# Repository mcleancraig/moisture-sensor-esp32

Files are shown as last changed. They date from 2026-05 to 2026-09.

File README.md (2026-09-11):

# Garden Soil Moisture Sensor

Battery-powered wireless soil moisture sensors for garden and indoor plant use. Each unit reads capacitive soil moisture and battery level, publishing data over WiFi/MQTT to a home automation hub. Designed for long-term deployment — estimated 5+ months per charge on a 2000mAh 18650 cell.

Built around the Seeed XIAO ESP32-C6, configured entirely via a captive portal web interface with no hardcoded credentials. Integrates natively with Home Assistant via MQTT autodiscovery.

---

## Features

- Capacitive soil moisture reading (0–100%)
- Battery voltage and percentage monitoring
- WiFi provisioning via captive portal — no hardcoded credentials
- Static or DHCP IP addressing, with configurable gateway, subnet and DNS
- Home Assistant MQTT autodiscovery — sensors appear automatically, autodiscovery republishes daily to recover from broker restarts
- Automatic firmware updates via FOTA from GitHub Releases, with rollback guard after 3 failed boots
- Beta FOTA channel — switch individual sensors between stable and beta firmware streams via Home Assistant
- Sensor power-gating — GPIO cuts HW-390 power during deep sleep, eliminating standby drain
- Syslog — structured UDP syslog to a configurable host for centralised logging
- Boot button reconfiguration — no reflashing needed to change settings
- MQTT command support — send `reset` remotely via retained message
- Deep sleep between readings — configurable interval (default 120 minutes) for long battery life
- First boot delay — skips moisture on first wake (default 15 minutes) so an open-air reading isn't sent while planting
- NTP timestamp in every MQTT payload
- Firmware version reported in every MQTT payload

---

## Wiring diagram

Wiring diagram

---

## Hardware

### Per sensor

| Component | Detail |
|---|---|
| MCU | Seeed XIAO ESP32-C6 |
| Moisture sensor | HW-390 capacitive, 3-pin (VCC / GND / AOUT) |
| Battery | 18650 Li-ion, 2000mAh recommended |
| Reverse polarity protection | None currently — P-channel MOSFET planned (see TODO) |
| Battery voltage divider | 2x 200kOhm resistors (BAT+ to A0 to GND) |
| Sensor power-gating | HW-390 VCC to D4 (GPIO4); configure `sensorPowerPin` in portal |

### Wiring

```
18650 (+) ──────────────────────────── XIAO BAT+ pad
                                        └── 200kOhm ── A0 ── 200kOhm ── GND

18650 (−) ────────────────────────────── XIAO BAT− pad ── GND

HW-390 VCC  ── XIAO D4 (GPIO4)    ← power-gated (see note)
HW-390 GND  ── GND
HW-390 AOUT ── XIAO A1 (GPIO1)
```

After first boot, set **Sensor Power Pin** to `4` in the config portal. The firmware drives D4 HIGH just before the ADC read and LOW before sleeping, so the HW-390 draws no current during deep sleep. Any free GPIO 0–10 can be used; D4 is recommended as it is otherwise unused.

If power-gating is not wired, connect HW-390 VCC to XIAO 3V3 instead and leave Sensor Power Pin at `-1` (default).

The XIAO's onboard charger handles battery charging automatically when USB-C is connected. USB and battery can be connected simultaneously — this is normal and required for charging.

**Note:** No reverse polarity protection is currently fitted. Always check battery orientation before connecting.

---

## Software requirements

### Arduino IDE

Install via the Boards Manager: **esp32 by Espressif Systems**

Board selection: `XIAO_ESP32C6`

### Libraries

Install via the Library Manager:

- **PubSubClient** by Nick O'Leary

All other libraries (`WiFi`, `WebServer`, `DNSServer`, `Preferences`, `HTTPUpdate`, `WiFiClientSecure`, `ESPmDNS`) are included in the ESP32 Arduino core.

---

## Building and flashing

1. Open `moisture-sensor-esp32.ino` in Arduino IDE
2. Select board: **Tools → Board → XIAO_ESP32C6**
3. Connect the sensor via USB-C
4. Select the USB port under **Tools → Port**
5. Click **Upload**

No configuration changes are needed before flashing — all settings are entered via the captive portal after first boot.

---

## First-time setup

On first boot (or after a factory reset), the sensor starts a WiFi access point named:

```
MOISTURE-AABBCC
```

where `AABBCC` is the last three bytes of the device's MAC address in hex.

**To configure:**

1. Connect to the `MOISTURE-` network — password is `moisture`
2. A setup page will appear automatically (captive portal). If it does not, open a browser and navigate to `192.168.4.1`
3. Fill in the form:
   - **Sensor number** — sets the sensor ID (`sensor1`, `sensor2` etc), friendly name, and default static IP last octet
   - **WiFi SSID and password** — your home network credentials
   - **Static IP** — optional. Check the box to assign a fixed IP address. Defaults to `192.168.220.<sensor number>`. When enabled, also configure gateway, subnet mask and DNS
   - **MQTT broker address** — IP address of your MQTT broker (e.g. your Raspberry Pi)
   - **MQTT port** — default 1883
   - **MQTT username / password** — leave blank if your broker does not require authentication
4. Click **Save & Restart**

The sensor will restart, connect to your network, and begin reporting immediately.

**First boot delay:** on the first wake after power-on or portal save, the sensor skips the moisture reading and sleeps for 15 minutes before taking its first full reading. This prevents a misleading open-air reading being sent to Home Assistant while you're getting the sensor into the soil. Battery stats are still published on that first wake. The delay is configurable (0–120 minutes) via the **First Boot Delay** entity in Home Assistant, or disabled by setting it to 0.

If the portal is not used within 10 minutes it will close, the sensor sleeps for 10 minutes, then restarts and tries WiFi again. If WiFi fails on a configured sensor, the portal opens automatically so you can update credentials.

---

## Reconfiguring a deployed sensor

### Boot button (physical access required)

1. Power the sensor on while holding the **boot button** on the XIAO board
2. Hold for 3 seconds until the serial monitor shows `Config — confirmed, clearing config`
3. Release the button — the sensor starts the configuration portal

A brief press under 3 seconds is ignored — normal boot continues.

### MQTT command (fully remote)

Publish a retained message to `garden/sensorN/cmd`. The sensor receives it on its next wake cycle, self-clears the retained message, then acts on it:

```bash
# Reset config and open portal:
mosquitto_pub -h localhost -u USER -P PASS \
  -t "garden/sensor1/cmd" -m "reset" --retain

# Cancel a pending command:
mosquitto_pub -h localhost -u USER -P PASS \
  -t "garden/sensor1/cmd" -m "" --retain
```

From Home Assistant **Developer Tools → Actions → mqtt.publish**:

```yaml
topic: garden/sensor1/cmd
payload: reset
retain: true
```

---

## Home Assistant integration

The sensor uses MQTT autodiscovery. Once MQTT is configured in Home Assistant:

1. Go to **Settings → Devices & Services → MQTT**
2. Ensure **Enable discovery** is checked and the discovery prefix is `homeassistant`
3. On next sensor boot, a new device will appear automatically under **Settings → Devices**

Each sensor creates these entities in Home Assistant:

**Sensors**

| Entity | Unit | Notes |
|---|---|---|
| Moisture | % | Soil moisture level |
| Battery | % | Estimated charge remaining |
| Battery Voltage | V | Raw cell voltage |
| Last Seen | — | NTP timestamp of last reading (UTC) |
| Firmware Version | — | Running firmware version |
| RSSI | dBm | WiFi signal strength at time of reading |
| Battery Low | — | Binary sensor — ON when battery ≤ 15% |

**Controls**

| Entity | Type | Notes |
|---|---|---|
| Reset Config | Button | Clears NVS and opens captive portal on next wake |
| Force check on next wake | Button | Bypasses the 24 h FOTA throttle — triggers an immediate update check |
| Sleep Interval | Number (1–720 min) | Wake cycle duration; default 120 min |
| First Boot Delay | Number (0–120 min) | Delay before first moisture read; default 15 min |
| Update Channel | Select (stable/beta) | FOTA release stream for this sensor |
| Static IP | Switch | Enable/disable static IP addressing |
| MQTT Broker / Port / Username / Password | Text/Number | Remote MQTT config update |
| Syslog Host / Port | Text/Number | Remote syslog config update |
| IP Address / Gateway / Subnet Mask / DNS | Text | Remote network config update |
| Moisture Pin / Battery Pin / Sensor Power Pin | Number | GPIO pin assignments |

The device card also shows the firmware version (`sw_version`) on the device info page.

### MQTT topics

| Topic | Direction | Content |
|---|---|---|
| `garden/sensor1/state` | Sensor → broker | JSON state payload |
| `garden/sensor1/cmd` | Broker → sensor | Command: `reset` (retained) |
| `homeassistant/sensor/sensor1_moisture/config` | Sensor → broker | HA discovery config (retained) |
| `homeassistant/sensor/sensor1_battery_pct/config` | Sensor → broker | HA discovery config (retained) |
| `homeassistant/sensor/sensor1_battery_v/config` | Sensor → broker | HA discovery config (retained) |
| `homeassistant/sensor/sensor1_ts/config` | Sensor → broker | HA discovery config (retained) |
| `homeassistant/sensor/sensor1_fw/config` | Sensor → broker | HA discovery config (retained) |
| `homeassistant/sensor/sensor1_rssi/config` | Sensor → broker | HA discovery config (retained) |
| `homeassistant/binary_sensor/sensor1_battery_low/config` | Sensor → broker | HA discovery config (retained) |
| `homeassistant/button/sensor1_reset/config` | Sensor → broker | HA discovery config (retained) |
| `homeassistant/button/sensor1_update_check/config` | Sensor → broker | HA discovery config (retained) |
| `homeassistant/select/sensor1_fw_channel/config` | Sensor → broker | HA discovery config (retained) |
| `garden/sensor1/update` | Broker → sensor | Retained `1` — forces FOTA check on next wake |

### State payload example

```json
{
  "sensor": "sensor1",
  "moisture": 65,
  "moisture_raw_mv": 1843,
  "dry_mv": 2800,
  "wet_mv": 1000,
  "battery_v": 3.87,
  "battery_pct": 62,
  "battery_raw_mv": 1935,
  "rssi": -67,
  "fw_version": "3.0.2-b01",
  "ts": "2026-05-04T14:32:07Z"
}
```

---

## Firmware updates (FOTA)

On each wake the sensor checks GitHub Releases for a newer firmware version and updates itself automatically. No IDE or physical access needed.

**To release a firmware update:**

1. Bump `FIRMWARE_VERSION` in the sketch
2. Run `build.sh` to compile — output is `build/moisture-sensor-esp32.ino.bin`
3. Create a plain text file `version.txt` containing just the new version number (e.g. `3.0.2`) with no trailing newline
4. Create a new GitHub release tagged `vX.X.X`, attach both `moisture-sensor-esp32.ino.bin` and `version.txt` as release assets
5. Every sensor will pick up the update automatically on its next wake cycle

The `fw_version` field in the MQTT payload confirms the running firmware version. If an update fails the sensor continues operating on the existing firmware and retries on the next wake.

**FOTA rollback guard:** after a FOTA flash, the firmware counts consecutive failed boots (defined as wakes that do not complete a successful MQTT publish). After 3 failures it switches back to the previous OTA partition and logs `FOTA — ROLLED BACK` via syslog. The rejected version is blocked from re-downloading.

**Update Channel:** each sensor can independently follow the `stable` channel (GitHub Releases marked *Latest*) or the `beta` channel (most recent release including pre-releases). Switch a sensor by changing its **Update Channel** entity in Home Assistant — the new value is written to NVS on next wake. Default is `stable`.

**Force check on next wake:** pressing the **Force check on next wake** button in HA publishes a retained `1` to `garden/sensorN/update`. The sensor reads this on its next wake, clears the retained message, and runs a FOTA check immediately regardless of the 24 h throttle.

**Tagging and releasing from the command line:**

```bash
git tag -a v3.0.3 -m "v3.0.3 release notes here"
git push origin v3.0.3
```

Then on GitHub go to **Releases → Draft a new release**, select the tag, and attach `moisture-sensor-esp32.ino.bin` and `version.txt`.

---

## Beta releases

Riskier changes can be shipped to a subset of sensors first via the **beta FOTA channel** before promoting to the whole fleet. The two channels read different sources, which is why their release assets differ:

| Channel | Reads | Assets required |
|---|---|---|
| `stable` | `/releases/latest/download/version.txt`, then the binary from the same release | `moisture-sensor-esp32.ino.bin` **and** `version.txt` |
| `beta` | `tag_name` of the newest release via the GitHub API, including pre-releases | `moisture-sensor-esp32.ino.bin` only |

**To cut a beta:**

1. On the version branch (not `main`), set `FIRMWARE_VERSION` to `X.Y.Z-bNN` — e.g. `3.0.3-b01`; bump `NN` for a respin
2. Tag and push: `git tag -a v3.0.3-b01 -m "..." && git push origin v3.0.3-b01`
3. Draft a release from that tag, tick **Set as a pre-release**, and attach the `.bin`. No `version.txt` needed — the beta channel never reads it, and `/releases/latest` skips pre-releases so stable sensors are unaffected
4. Sensors with **Update Channel** set to `beta` pick it up on their next wake

**To promote a confirmed beta to stable:**

1. On the version branch, drop the `-bNN` suffix from `FIRMWARE_VERSION`
2. Finalise the `CHANGELOG.md` entry
3. Open the final PR from the version branch into `main` and merge
4. Tag and release as normal (`vX.Y.Z`, *not* a pre-release), attaching both the `.bin` and `version.txt`

`isNewerVersion()` treats a stable build as newer than a beta of the same version, and a higher `-bNN` as newer than a lower one, so promoting to stable is picked up automatically and switching a sensor's channel back and forth needs no version bump.

**Attach the binary before publishing, not after.** The beta channel bypasses the 24 h FOTA throttle, so a published pre-release with no `.bin` attached leaves beta sensors retrying a 404 on *every* wake.

**Verify the binary before uploading** — confirm the version baked into it matches the tag:

```bash
grep -a -o '3\.0\.3[^"]*' build/moisture-sensor-esp32.ino.bin | sort -u
```

A mismatch here means every sensor will download the "new" firmware, boot into the old version, see an update available again, and reflash indefinitely.

**Beta sensors park when no pre-release is newest.** If the most recent release is a stable one, beta-channel sensors log `FOTA — no beta release available yet, staying put` and hold their current build rather than moving to the stable. To bring them back in line with the fleet, switch their **Update Channel** to `stable`.

---

## Syslog

The sensor buffers log messages during its wake cycle and flushes them over UDP syslog after WiFi connects. This gives centralised, structured logging without a serial connection.

**Configuration:** set `Syslog Host` and `Syslog Port` in the captive portal, or update them remotely via the corresponding HA entities. Default port is `514`. Leave `Syslog Host` blank to disable syslog.

**Behaviour:**
- All `logf()` calls are buffered in RAM during boot and WiFi connection
- After WiFi connects the buffer is flushed: each entry is sent as a syslog UDP packet to the configured host
- If DNS resolution fails for the syslog host the buffer is discarded and syslog is skipped for that cycle (no startup delay)
- After flush, any subsequent log calls are sent immediately

**Useful log patterns:**
- `FOTA      — ROLLED BACK` — firmware rollback guard fired; investigate what changed
- `Discovery — skipped (3.0.3, NNm ago)` — discovery republish throttled; expected on most wakes
- `FOTA      — forced check` — triggered by the Force check HA button
- `WiFi      — connected, IP: … (312ms, cached)` — association time, and whether the cached BSSID or a full scan was used. A sensor logging `full scan` every wake is not benefiting from the connection cache
- `WiFi      — fast connect failed, retrying full scan connect` — the cached AP moved channel or went away; self-corrects, but persistent occurrences suggest an unstable AP or roaming between mesh nodes
- `Sleep     — awake NNNNms this wake` — total awake duration. The single most useful number for tracking per-wake energy use across the fleet
- `MQTT      — listen window closed after NNNms (N message(s) this wake)` — confirms remote commands are arriving inside the listen window

---

## Moisture sensor calibration

The HW-390 sensor must be calibrated once per unit for accurate percentage readings. The raw millivolt values are included in every MQTT payload (`moisture_raw_mv`) to assist with this.

**Calibration procedure:**

1. Flash the firmware and configure the sensor
2. Hold the sensor in open air — note the stable `moisture_raw_mv` value. Set this as `DRY_MV` in the firmware (typically ~2800mV)
3. Submerge the sensor to the white line marked on the PCB — note the stable value. Set this as `WET_MV` (typically ~1000mV)
4. Reflash with updated values

The HW-390 is inverted: dry soil reads a higher millivolt value than wet soil. `DRY_MV` should always be greater than `WET_MV`.

---

## Battery life

Based on a 120-minute sleep cycle (default) and 2000mAh cell:

| Phase | Current | Duration per cycle |
|---|---|---|
| Deep sleep | ~15uA | ~7,195 seconds |
| WiFi + MQTT | ~300mA peak | ~3 seconds |
| FOTA version check | ~80mA | ~2 seconds (no download if firmware is current) |

Estimated runtime: **5+ months** per charge. Actual runtime depends on WiFi signal strength, temperature, and cell quality.

The awake duration above is an estimate. Since v3.0.3 the real figure is logged every wake as `Sleep — awake NNNNms this wake`, so per-sensor energy use can be measured from syslog rather than assumed — worth checking against this table before making further power optimisations. Note that at a 120-minute interval, standby losses (deep sleep current, the 400 kΩ battery divider, regulator quiescent draw and cell self-discharge) are a substantial share of the budget, so reducing awake time has diminishing returns compared with cutting standby draw.

The battery percentage uses a piecewise linear interpolation of a real 18650 discharge curve, giving accurate readings across the full voltage range rather than fixed steps.

---

## Factory reset

To completely clear all configuration and return to first-boot state:

- **Via MQTT:** send a retained `reset` command (see Reconfiguring a deployed sensor above) — no physical access needed
- **Via boot button:** power the sensor on while holding the boot button for 3 seconds — the firmware clears NVS and starts the configuration portal. No reflashing required

---

## Deploying multiple sensors

Each sensor needs only one change — the sensor number is set during portal configuration and everything else derives from it automatically:

| Sensor number | Sensor ID | MQTT topic | Default static IP |
|---|---|---|---|
| 1 | sensor1 | garden/sensor1/state | 192.168.220.1 |
| 2 | sensor2 | garden/sensor2/state | 192.168.220.2 |
| 3 | sensor3 | garden/sensor3/state | 192.168.220.3 |

Each sensor must be calibrated individually as HW-390 units vary slightly from one another.

---

## Troubleshooting

**Sensor not appearing in Home Assistant**
Ensure MQTT integration is enabled in HA and discovery is turned on. Check the broker is reachable and credentials are correct by monitoring `garden/#` on the broker directly:

```bash
mosquitto_sub -h localhost -t "garden/#" -v -u YOUR_USER -P YOUR_PASSWORD
```

**FOTA update not applying**
- Ensure the sensor has internet access — verify DNS is configured correctly in the portal
- Check the `fw_version` field in the MQTT payload to confirm what version is currently running, and the sensor's **Update Channel** to confirm which stream it is following
- *Stable channel:* confirm `version.txt` is attached to the latest GitHub release and contains the correct version string with no leading `v` and no trailing whitespace or newlines. A leading `v` will not parse and the sensor will never update
- *Beta channel:* confirm the newest release is marked as a pre-release. If the newest release is a stable one, beta sensors deliberately stay put — see [Beta releases](#beta-releases)

**Sensor reflashing on every wake**
The version baked into the released binary does not match the release it is attached to, so the sensor downloads it, boots reporting the old version, and immediately sees an update available again. Check syslog for a repeating `FOTA — update available: X -> Y` where `X` never changes, then verify the release asset as described under [Beta releases](#beta-releases) and re-upload a correctly built binary. Sensors recover on their own once the corrected asset is in place.

**Moisture reading stuck at 0% or 100%**
Recalibrate — the `DRY_MV` and `WET_MV` values in the firmware need to match your specific sensor unit. Check `moisture_raw_mv` in the MQTT payload and compare against your calibration readings.

**Battery reading shows null**
The battery reading falls outside the sanity check range (2.5V–4.3V). Check the voltage divider wiring — two 200kOhm resistors from BAT+ to A0 to GND. Confirm A0 is the pin connected to the midpoint, not A1.

**Sensor getting hot when USB connected**
Check battery polarity. Overheating is caused by reverse polarity on the battery connection, not by USB and battery being connected simultaneously. USB and battery can safely coexist — the onboard charger is designed for this. No polarity protection is currently fitted — always check battery orientation carefully before connecting.

---

## Licence

GPL V2 — see LICENSE.md

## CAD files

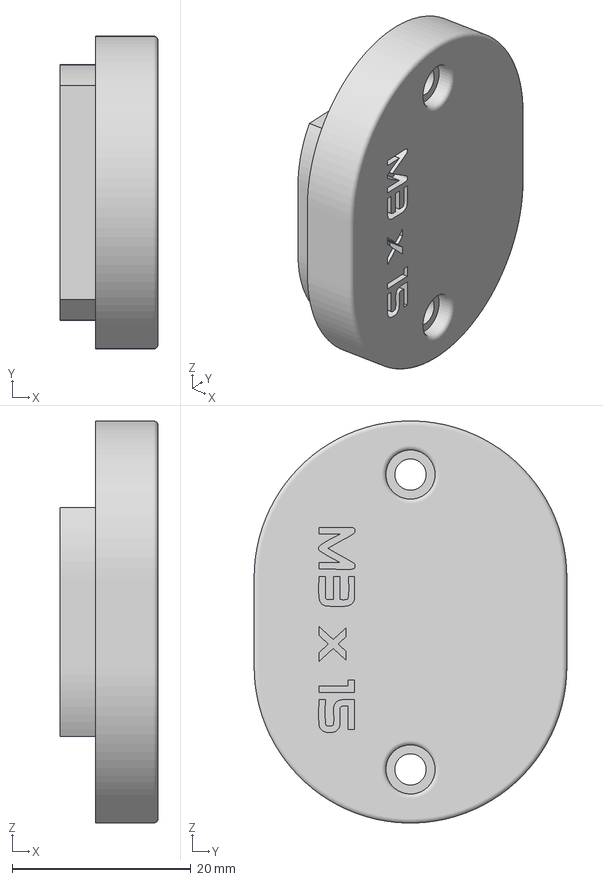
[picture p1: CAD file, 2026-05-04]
3d-printed-case/Lid.3mf
11.0 x 35.0 x 45.0 mm

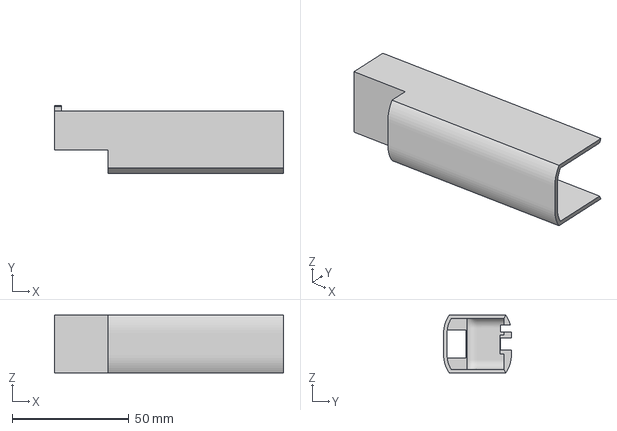
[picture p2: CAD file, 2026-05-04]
3d-printed-case/Tray.3mf
98.0 x 29.0 x 24.7 mm

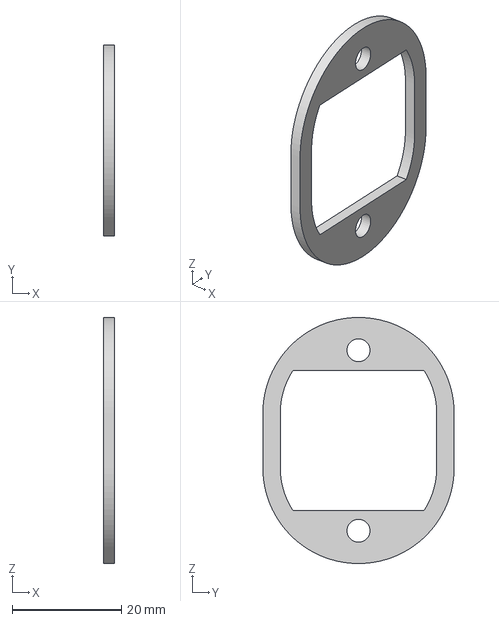
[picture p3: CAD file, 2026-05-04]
3d-printed-case/Seal.3mf
2.00 x 35.0 x 45.0 mm

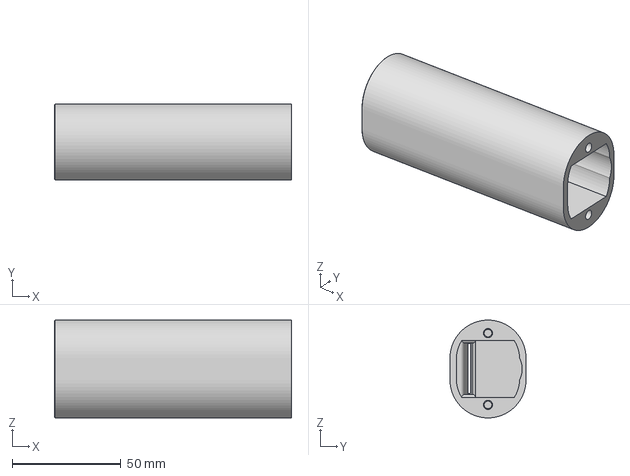
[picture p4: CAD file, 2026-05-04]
3d-printed-case/Case.3mf
109.0 x 35.0 x 45.0 mm

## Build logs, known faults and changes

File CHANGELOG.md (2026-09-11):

# Changelog

All notable changes to moisture-sensor-esp32 are documented here.
Format follows [Keep a Changelog](https://keepachangelog.com/).

## [3.0.3] — 2026-09-11

### Fixed
- **HA discovery republished on every wake** — the safety-net threshold was `> 2h`, exactly equal to the default `SLEEP_MINUTES` of 120, so elapsed time always exceeded it and the throttle never fired. Roughly 20 retained discovery payloads were being republished every wake instead of acting as an occasional recovery mechanism, and the `Discovery — skipped` log line was effectively unreachable. Now governed by `DISCOVERY_REPUBLISH_S` (24h), which stays clear of the longest configurable `sleepMinutes` (720).

### Changed
- **MQTT listen window shortened, 2000ms → 750ms** — retained commands are delivered within tens of milliseconds of SUBACK, so the old fixed 2s window spent most of its time idle at full radio power. Each inbound message now extends the window by 250ms (capped at 2000ms, the previous fixed value), so a burst of `config/set` fields published together is still captured in a single wake. Worst-case awake time is unchanged; typical awake time drops by ~1.25s per wake.

### Added
- **Wake timing instrumentation** — `WiFi — connected` now reports association time and whether the cached BSSID or a full scan was used; a new `Sleep — awake Nms this wake` line reports total awake duration. Both are intended for measuring per-wake energy across the fleet from syslog.

### Upgrade notes
- Discovery now republishes at most daily rather than every 2 hours. After an MQTT broker restart that loses retained messages, Home Assistant may show a sensor as unavailable for up to 24h. A firmware update or power cycle forces an immediate republish, as before.

## [3.0.1-b02] — 2026-07-04

### Added
- **Captive Portal Update Channel Selection (`fwChannel`)** — Exposed the 'Update channel' selection dropdown (stable/beta) in the captive portal's Advanced Settings. Dynamically pre-selects 'beta' on setup if booting a pre-release/beta build (preventing accidental downgrades back to stable), while giving the user full control to save their preferred channel.

### Removed
- **Unused Reed Switch Code** — Completely removed the unused reed switch monitoring, including the configuration struct parameter, load/save logic, captive portal form inputs, JavaScript client-side validation, server-side parsing, dynamic MQTT parsing, and the `checkReedSwitch()` function. Physical pin **D2** (GPIO 2) is now completely clean and unassigned, making it 100% safe to configure as the **Sensor Power Pin** to power-gate the soil moisture sensor without boot loop risks or false conflict checks.

## [3.0.1-b01] — 2026-07-04

### Added
- **Configurable On-Demand Sensor Power Pin (`sensorPowerPin`)** — Adds support for powering the soil moisture sensor via a configurable GPIO pin (NVS key `powerPin`, defaults to `-1` for continuous rail power).
- **Parallel Power Stabilization** — Drives the sensor power pin `HIGH` early during boot to overlap the 500ms stabilization period with other boot checks, minimizing wake time. Bypasses the 500ms delay and uses a quick 200ms settling window when running off the continuous rail.
- **Deep Sleep Tri-stating** — Drives the power pin `LOW` and sets it to high-impedance `INPUT` mode (tri-state) during deep sleep to completely eliminate parasitic leakage current.
- **Beta FOTA Rate-Limit Bypass** — Bypasses the 24-hour rate limit gate for sensors subscribed to the `beta` update channel or running a beta/dev firmware version, allowing update checks on every boot.

### Changed
- **Smart Pin-Conflict Checking** — Updated both boot validation, captive portal client/server validation, and MQTT remote config pin conflict checking to safely skip negative (disabled) pins, preventing false conflicts.

## [3.0.0] — 2026-07-04

### Added
- **Wi-Fi Fast Connect Caching** — Implemented caching of successful Wi-Fi channel and BSSID in RTC SRAM. Speeds up subsequent connection attempts to ~200ms under optimal conditions.
- **Deep Sleep GPIO Pull-up Hold** — Maintains the Reed switch internal pull-up during deep sleep to prevent spurious wakeups, using conditional compilation to support the ESP32-C6's single-pin hold mechanism.
- **Sleep Interval MQTT/HA control** — `config/set/sleepMinutes` and a "Sleep Interval" number entity (1-720 min) let you change how long the sensor sleeps between wake cycles without reflashing.

### Changed
- **Home Assistant Discovery Topic Refactoring** — Removed 25 redundant global `char[128]` buffer arrays, saving **3,200 bytes of permanent dynamic RAM (BSS)**. Discovery topics are now formatted dynamically on-the-fly.
- **Shared Device JSON Helper** — Extracted duplicate Home Assistant `device` JSON construction logic into a static `getDeviceJSON()` helper function, saving **914 bytes of program Flash memory**.
- **Consolidated Telemetry JSON Construction** — Replaced three duplicate, verbose `snprintf()` blocks in `setup()` with a clean conditional single-pass composer, reducing Flash footprint.
- **Log Buffer & Stack Optimization** — Removed the redundant `char sysline[120]` stack buffer from `_logf()`, reducing active stack overhead by **120 bytes** for all print operations.
- **Secure FOTA Certificate Bundle** — Replaced `client.setInsecure()` with secure validation using ESP32's built-in root CA certificate bundle (`esp_crt_bundle_attach` via a `SecureClient` wrapper) to properly and safely validate HTTPS connections and redirects.
- **"Update on next wake" button renamed "Force check on next wake"** — Renamed this control under a clearer name.

### Removed
- **Restart MQTT/HA control** — the Restart button and `garden/sensorN/cmd` `restart` command are gone. No longer applicable now the device already restarts every wake as part of its normal sleep cycle. `reset` (full config wipe + portal) is unaffected.
- **Reed Switch Pin MQTT/HA control** — the "Reed Switch Pin" number entity and `config/set/reedPin` are gone. `reedPin` is now portal-only, matching `wifiSSID`/`unitNumber`. The reed switch itself (hold 3s to restart, hold 10s to wipe config, GPIO wakeup) is unchanged.

### Upgrade notes
- After every sensor is running v3.0.0+, run `cleanup-mqtt-retained.sh` against your broker to clear the retained Restart button discovery config and the Reed Switch Pin discovery config — neither is republished or cleared automatically by the firmware change alone.

## [3.0.0-b04] — 2026-07-04

### Changed
- **Home Assistant Discovery Topic Refactoring** — Removed 25 redundant global `char[128]` buffer arrays, saving **3,200 bytes of permanent dynamic RAM (BSS)**. Discovery topics are now formatted dynamically on-the-fly.
- **Shared Device JSON Helper** — Extracted duplicate Home Assistant `device` JSON construction logic into a static `getDeviceJSON()` helper function, saving **914 bytes of program Flash memory**.
- **Consolidated Telemetry JSON Construction** — Replaced three duplicate, verbose `snprintf()` blocks in `setup()` with a clean conditional single-pass composer, reducing Flash footprint.
- **Log Buffer & Stack Optimization** — Removed the redundant `char sysline[120]` stack buffer from `_logf()`, reducing active stack overhead by **120 bytes** for all print operations.

## [3.0.0-b03] — 2026-07-04

### Added
- **Wi-Fi Fast Connect Caching (Optimization 2)** — Implemented caching of successful Wi-Fi channel and BSSID in RTC SRAM. Speeds up subsequent connection attempts to ~200ms under optimal conditions, falling back to a full scan if fast connect fails within 4 seconds.
- **Deep Sleep GPIO Pull-up Hold (Optimization 4)** — Maintains the Reed switch internal pull-up during deep sleep to prevent spurious wakeups, using conditional compilation to support the ESP32-C6's single-pin hold mechanism.

### Changed
- **Secure FOTA Certificate Bundle (Optimization 3)** — Replaced `client.setInsecure()` with secure validation using ESP32's built-in root CA certificate bundle (`esp_crt_bundle_attach` via a `SecureClient` wrapper) to properly and safely validate HTTPS connections and redirects.

## [2.11.0] — 2026-07-01

### Fixed
- **NVS magic regression (v2.10.2)**: absent magic (sensors configured before v2.5.3 that never triggered a config change post-upgrade) now proceeds normally again instead of wiping NVS. Magic is written passively at the end of a successful `loadConfig()` so the migration happens on the next boot without any portal interaction. Wrong-value magic still wipes NVS as before.
- **First boot delay disabled after portal re-provision**: `handleSave()` was copying `firstBootDelayMin` from `cfg` even when `loadConfig()` had returned early (after a magic wipe), leaving `cfg` zero-initialised and silently saving `firstBootDelayMin = 0`. Now uses the 15-minute default when config was never loaded, preserving an explicit user value when it was.

### Changed
- **Portal AP name**: shortened from full 12-char MAC (`MOISTURE_AABBCCDDEEFF`) to last-3-bytes short form (`MOISTURE-DDEEFF`) — unique per device, much easier to distinguish when multiple sensors are in portal mode simultaneously.
- **Boot logging**: `reset_reason` now includes human-readable string (`POWERON`, `SW`, `PANIC`, `WDT`, `BROWNOUT`, …). A new log line on cold boots and portal-restarts confirms whether the first boot delay is active and the configured value.
- **Sleep log reliability**: `goToSleep()` now waits 50 ms after logging before calling `esp_deep_sleep_start()`, giving the final syslog UDP packet time to transmit before the radio shuts down.

## [2.10.2] — 2026-05-27

### Changed
- NVS magic check tightened: absent magic key now clears the namespace and falls through to portal, matching the behaviour for a wrong-value magic key. Previously, absent magic was left alone for backwards compatibility with pre-2.5.3 sensors. All deployed sensors have run 2.5.3+ for some time.

## [2.10.1] — 2026-05-27

### Fixed
- `handleSave()` built `Config c = {}` (zero-initialised), saving `firstBootDelayMin = 0` to NVS and discarding the 15-minute default. Fixed: `handleSave()` now copies `firstBootDelayMin` from `cfg` before saving.
- Post-portal `ESP.restart()` gives `reset_reason = SW (3)`, not `POWERON (1)`, so the first operational boot after configuring a new sensor never triggered the delay. Fixed with a one-shot NVS flag (`firstBootPend`) set by `handleSave()` and atomically read and cleared by `checkAndClearFirstBootPending()` at next boot.

## [2.10.0] — 2026-05-27

### Added
- **First boot delay** — on power-cycle (`ESP_RST_POWERON`) or immediately after portal configuration, the device publishes all stats except moisture then sleeps for `firstBootDelayMin` (default 15 minutes) before waking for the first full reading. Prevents a spurious near-zero moisture reading while the sensor is still in open air after battery insertion.
- `firstBootDelayMin` config field (NVS key `firstBootMin`, default 15, range 0–120 minutes). Set to 0 to disable.
- HA `First Boot Delay` number entity (0–120 min) via autodiscovery.
- MQTT remote config: `config/set/firstBootDelayMin` — same pattern as all other configurable fields.

### Changed
- `goToSleep()` now takes an explicit `int minutes` parameter (was hardcoded to `SLEEP_MINUTES`).

## [2.9.0] — 2026-05-16

### Changed
- `sensorNumber` renamed to `unitNumber` in config struct for cross-repo consistency (NVS key `sensorNum` unchanged — no factory reset required)
- State payload field `"fw"` renamed to `"fw_version"` — update any HA value templates that reference `value_json.fw`
- FOTA version comparison now uses integer semver parsing — fixes `"2.10.0" < "2.9.0"` bug under lexicographic `strcmp`
- Beta channel FOTA now uses strict `isNewerVersion()` instead of `!=` — prevents downgrade if remote beta is older

### Added
- `"rssi"` field in state payload (WiFi RSSI in dBm)
- Full wake-reason switch: timer, GPIO, and unexpected causes all logged with reason codes
- `esp_reset_reason()` logged at boot — surfaces panics, WDT resets, and brownouts in syslog
- Heap monitoring: free + minimum free heap logged after WiFi connects and after FOTA check
- `validateConfig()` called at boot to warn of GPIO pin conflicts
- `"MQTT — HA discovery published"` log line after all discovery payloads sent
- MQTT connect log now includes port number
- `*.bin` added to `.gitignore`
- `CHANGELOG.md` and `build.sh`

## [2.8.0] — 2026-05-15

### Added
- Beta FOTA channel — opt sensors into pre-releases via HA select entity
- Force-update via MQTT — `garden/sensorN/update` retained flag triggers immediate FOTA check on next wake
- HA button entity for firmware update

### Changed
- Sleep interval restored to 120 minutes
- FOTA moved after MQTT listen phase so force-update command takes effect same wake

## [2.7.0]

### Changed
- NTP re-sync skipped when RTC already holds valid time (saves ~8 s per wake)
- FOTA version check throttled to once per 24 h via RTC memory timestamp
- HA discovery publish skipped on normal deep-sleep wakes (republishes on cold boot or after 7 days)

## [2.6.2]

### Changed
- Sleep interval increased from 15 to 120 minutes

## [2.6.1]

### Fixed
- Reed switch default pin changed from GPIO3 to GPIO2 (GPIO3 non-functional as digital input on XIAO ESP32-C6)

## [2.6.0]

### Added
- Reed switch GPIO wakeup — device wakes within ms of magnet contact, enabling reliable 3 s/10 s hold timing

## [2.5.3]

### Added
- NVS magic key validation — detects stale config from foreign firmware and falls through to portal

[2.11.0]: https://github.com/mcleancraig/moisture-sensor-esp32/releases/tag/v2.11.0
[2.10.2]: https://github.com/mcleancraig/moisture-sensor-esp32/releases/tag/v2.10.2
[2.10.1]: https://github.com/mcleancraig/moisture-sensor-esp32/releases/tag/v2.10.1
[2.10.0]: https://github.com/mcleancraig/moisture-sensor-esp32/releases/tag/v2.10.0
[2.9.0]: https://github.com/mcleancraig/moisture-sensor-esp32/releases/tag/v2.9.0
[2.8.0]: https://github.com/mcleancraig/moisture-sensor-esp32/releases/tag/v2.8.0

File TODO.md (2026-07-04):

# TODO — v3 and beyond

Items identified during v2 development for future releases.

## Security

- [ ] **FOTA TLS certificate validation** — `checkForUpdate()` currently uses `client.setInsecure()`, which skips certificate verification. An MITM on the network path between the sensor and GitHub could serve a malicious firmware binary that the device would flash without question. Fix: embed the ISRG Root X1 CA certificate (~1.5 KB of flash) and call `client.setCACert(rootCA)` instead. This secures the entire download path without requiring manual cert rotation.

- [ ] **FOTA firmware integrity check** — even with TLS validation, publishing a SHA-256 hash of `firmware.bin` as a third release asset and verifying it before flashing would provide defence-in-depth against a compromised GitHub account or release. Requires downloading the binary manually rather than via `httpUpdate`, then verifying the hash before calling `Update.begin()`.

- [ ] **P-channel MOSFET reverse polarity protection** — replace the removed 1N5819 diode with a P-channel MOSFET (e.g. AO3401) wired as a reverse polarity switch. Unlike the diode this has near-zero voltage drop and allows bidirectional current, meaning charging works correctly while still protecting against reversed battery insertion. The 1N5819 diode blocked charging current and has been removed from the design pending this fix.

## Maintainability

- [x] **NVS magic — migrate pre-2.5.3 sensors (v2.11.0)** — v2.10.2's clear-on-absent tightening turned out to wipe sensors that had run pre-2.5.3 firmware and never since triggered a config save, so v2.11.0 reverted it: absent magic now proceeds normally and is written passively at the end of a successful `loadConfig()`, migrating those sensors on their next boot with no portal interaction. Wrong-value magic still clears NVS as before.

- [x] **FOTA (v2.1.0)** — sensors automatically check GitHub Releases on each wake and self-update. Attach `version.txt` and `firmware.bin` to each release. IDE-based OTA removed.

- [ ] **PCB design** — replace breadboard/perfboard wiring with a custom 2-layer PCB. Castellated footprint for the XIAO ESP32-C6, HW-390 JST connector, 2x 200k voltage divider resistors, 100nF bypass cap, BAT+/BAT- pads. Fabricate via JLCPCB. Reduces assembly time per unit from ~30 min to ~5 min.

## Power

- [ ] **Power-gate the soil moisture sensor** — the HW-390's VCC is wired directly to the 3V3 rail, drawing 5–10 mA continuously including during deep sleep. Fix: wire sensor VCC to a free GPIO (e.g. GPIO4), drive it HIGH just before the ADC read, wait ~80 ms to stabilise, sample, then pull LOW before sleeping. Reduces deep-sleep current from ~5000 µA to ~20 µA — a 99.6% saving. Add `moisturePowerPin` as a config field (portal + NVS) so the pin can be set per-unit without reflashing.

## Scalability

- [ ] **Zigbee mesh migration** — the ESP32-C6 supports Zigbee 3.0 natively. For deployments beyond 15 sensors, or where battery life becomes a concern, reflash units as Zigbee end devices with one unit acting as coordinator (USB-powered, connected to Pi). Requires ESP-IDF rather than Arduino. Zigbee transmit current is significantly lower than WiFi, extending battery life considerably.

## Nice to have

- [x] **Wiring diagram** — SVG diagram in repo showing XIAO ESP32-C6, 18650, HW-390, voltage divider, and reed switch. Photos still outstanding (see below).

- [-] ~~**Reed switch testing**~~ *(skipped)* — two-stage hold (3 s = restart, 10 s = wipe config) implemented in v2.4.1 but untested on real hardware.

- [ ] **Photos** — add photos of the assembled unit, enclosure, and deployed sensor to the README.

- [ ] **Calibration helper** — add a calibration mode triggered by double-tap of the boot button that holds the sensor awake, streams raw ADC readings over serial, and publishes min/max observed values to MQTT to assist with DRY_MV / WET_MV calibration without reflashing.

- [x] **Low battery alert** — binary sensor autodiscovery entity, reports ON at ≤ 15% (v2.4.1).

- [x] **FOTA downgrade protection** — implemented in v2.9.0; `isNewerVersion()` uses numeric semver comparison and only updates when remote > local.

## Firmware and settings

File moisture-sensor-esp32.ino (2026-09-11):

#include <WiFi.h>
#include <WiFiUDP.h>
#include <WebServer.h>
#include <DNSServer.h>
#include <Preferences.h>
#include <PubSubClient.h>
#include <HTTPUpdate.h>
#include <WiFiClientSecure.h>
#include <time.h>
#include "esp_mac.h"
#include "esp_sleep.h"
#include "esp_ota_ops.h"
#include "esp_partition.h"
#include <esp_crt_bundle.h>
#include <driver/gpio.h>

class SecureClient : public WiFiClientSecure {
public:
  void enableDefaultBundle() {
    attach_ssl_certificate_bundle(sslclient.get(), true);
    _use_ca_bundle = true;
    _use_insecure = false;
  }
};

// ═══════════════════════════════════════════════════════════
//  v3.0.2
//  - MQTT autodiscovery republish interval reduced from 7 days
//    to 2 hours. HA entities now recover within one wake cycle
//    after a broker restart or retained-message loss.
//  - Fix: %% corrected to % in moisture and battery_pct
//    unit_of_measurement discovery payloads. HA was rejecting
//    these entity configs due to the literal %% in the JSON.
//  - Fix: forward declarations added for _logf and hasValidEpoch
//    to allow compilation on Apple Silicon without Rosetta.
// ═══════════════════════════════════════════════════════════
//  v3.0.1
//  - Completely removed the unused Reed Switch code, including
//    the portal input fields, JavaScript/server-side validation,
//    dynamic MQTT configuration parsing, and the checkReedSwitch()
//    loop.
//  - Physical pin D2 (GPIO 2) is now fully unassigned and can
//    be safely used for sensor power gating (configured as Sensor
//    Power Pin = 2) without boot loop risks or conflict checks.
// ═══════════════════════════════════════════════════════════
//  v3.0.0
//  - Removed the Restart MQTT/HA control (button + garden/sensorN/cmd
//    "restart" command). No longer applicable now the device already
//    restarts every wake as part of the sleep cycle.
//  - Removed the Reed Switch Pin MQTT/HA control (config/set/reedPin +
//    HA number entity). The reed switch itself — hold-to-restart,
//    hold-to-wipe, GPIO wakeup, portal field — is unchanged; reedPin is
//    now portal-only, matching wifiSSID/unitNumber.
//  - Update-on-next-wake button renamed "Force check on next wake" for
//    clarity (b01 removed it, reasoning routine FOTA already checks every
//    wake — but that check is throttled to once per 24h, and this button
//    is the only way to bypass the throttle on demand, e.g. right after
//    cutting a beta for a test device. Restored in b02.)
//  - Added Sleep Interval MQTT/HA control (config/set/sleepMinutes,
//    "Sleep Interval" number entity, 1-720 min) — replaces the hardcoded
//    SLEEP_MINUTES constant as the default.
//  - See cleanup-mqtt-retained.sh to clear retained broker state left by
//    the Restart button, Reed Switch Pin control, and remote config command
//    topics once the fleet is on v3.0.1+.
//
//  v2.11.0
//  - NVS magic: revert v2.10.2 tightening for the absent-magic case.
//    Absent magic (pre-2.5.3 sensors that never called saveConfig()) now
//    proceeds normally again and writes magic at the end of a successful
//    loadConfig(). Wrong-value magic still clears NVS as before. This fixes
//    the v2.10.2 regression that wiped sensors configured before 2.5.3 that
//    had never triggered a config change since upgrading.
//  - First boot delay: fix handleSave() copying firstBootDelayMin from an
//    uninitialised cfg when loadConfig() returned early (magic wipe). Now
//    uses 15-minute default when config was never loaded, preserving an
//    explicit user setting when it was. This also fixes the linked issue
//    where post-wipe portal provisioning silently disabled the delay.
//  - Portal AP name: shortened from full 12-char MAC to last-3-bytes
//    (MOISTURE-AABBCC) — unique per device, easier to distinguish when
//    multiple sensors are in portal mode simultaneously.
//  - Boot logging: reset_reason now includes human-readable string
//    (POWERON, SW, PANIC, WDT, BROWNOUT, …). A new log line on cold
//    boots/portal-restarts confirms whether first boot delay is active and
//    the configured value — directly visible in syslog without inference.
//  - Sleep log: added delay(50) in goToSleep() to give the final syslog
//    UDP packet time to transmit before the radio shuts down.
//
//  v2.10.2
//  - NVS magic tightened: absent magic key (pre-2.5.3 sensors) now clears
//    the namespace and falls through to portal, matching the existing
//    wrong-value behaviour. Backwards-compatibility holdover removed now
//    that all deployed sensors have run 2.5.3+.
//
//  v2.10.1
//  - First boot delay bug fixes:
//    (a) handleSave() built Config c={} (zero-init), writing firstBootDelayMin=0
//        to NVS and discarding the 15-min default. Fixed: handleSave() now
//        copies firstBootDelayMin from the current cfg before saving.
//    (b) After portal config, ESP.restart() produces reset_reason=SW (3), not
//        ESP_RST_POWERON (1), so the post-portal boot never triggered the delay.
//        Fixed: handleSave() sets a one-shot NVS flag (firstBootPend); setup()
//        checks both ESP_RST_POWERON and that flag to determine isFirstBootDelay.
//
//  v2.10.0
//  - First boot delay: on power-cycle cold boot the device publishes all
//    stats except moisture, then sleeps for firstBootDelayMin (default 15)
//    before waking for the first full data set. This prevents a spurious
//    near-zero moisture reading while the sensor is still in open air after
//    battery insertion. firstBootDelayMin is configurable via HA/MQTT
//    (0 = disabled). Only triggered by ESP_RST_POWERON; warm resets and
//    deep-sleep wakes follow the normal cycle.
//
//  v2.9.0
//  - Cross-repo standardisation:
//    sensorNumber renamed to unitNumber (NVS key unchanged — no factory reset);
//    state payload fw → fw_version, add rssi field;
//    semver comparison fixed (strcmp fails when minor ≥ 10);
//    full wake/reset-reason logging (timer, GPIO, cold boot, panics);
//    heap monitoring at boot and post-FOTA;
//    validateConfig() pin-conflict check at boot;
//    HA discovery published log; MQTT connect log includes port.
//
//  v2.8.0
//  - Beta FOTA channel: sensors can be switched to "beta" update channel
//    via HA, which tracks GitHub pre-releases (tagged 2.8.0-b01 etc.) rather
//    than stable releases only. Version comparison on beta channel uses
//    "different = update" semantics; stable channel unchanged.
//  - Update on next wake: HA button publishes a retained MQTT flag to a
//    dedicated topic; device receives it on next wake, clears the flag, and
//    runs a FOTA check unconditionally (bypasses 24h gate and dev-build guard).
//  - FOTA moved to after the MQTT listen phase so the force-update command
//    received this wake takes effect this wake, not the next.
//  - fwChannel config field persisted in NVS; exposed as HA select entity.
//
//  v2.7.0
//  - Power optimisation: NTP re-sync skipped when ESP32 RTC already holds a
//    valid time from the previous cycle (deep sleep preserves RTC). Full NTP
//    sync forced once every 24 hours to correct clock drift.
//  - Power optimisation: FOTA version check throttled to once per 24 hours
//    via RTC memory timestamp. Eliminates a TLS connection (~8s) on every
//    wake when firmware is already current.
//  - Power optimisation: HA MQTT autodiscovery publish skipped on normal
//    deep-sleep wakes. Republishes on cold boot, OTA restart, firmware
//    version change, or if more than 7 days have elapsed (broker safety net).
//    Combined, these three changes save ~50-60% of active-cycle energy.
//
//  v2.6.2
//  - Sleep interval increased from 15 to 120 minutes to extend battery life.
//
//  v2.6.1
//  - Reed switch default pin changed from 3 to 2 — GPIO3 on XIAO ESP32-C6
//    does not function as a digital input; GPIO2 (D2) confirmed working.
//    Existing sensors are unaffected (reedPin stored in NVS).
//
//  v2.6.0
//  - Reed switch wakes device from deep sleep immediately on magnet contact
//    via esp_deep_sleep_enable_gpio_wakeup(). Previously the device only
//    checked the reed on the 15-minute timer tick, making the 3s/10s hold
//    timing impractical (user couldn't know when the check window started).
//    Now: magnet present → device wakes within ms → hold 3s to restart,
//    hold 10s to wipe config. Existing checkReedSwitch() timing unchanged.
//
//  v2.5.3
//  - NVS magic key: loadConfig() checks for "moisture-1" magic in the
//    "sensor" namespace; if a different value is found (stale NVS from
//    a foreign firmware), the namespace is cleared and the device falls
//    through to portal. Absent magic (pre-2.5.3 sensors) is left alone
//    for backwards compatibility — magic is written on next saveConfig().
//
//  v2.5.2
//  - MQTT password masked in publishConfigState() — publishes "***" instead
//    of the real credential to the retained config/state topic
//  - snprintf overflow: added publishMqttEntity() helper; both publishDiscovery()
//    and publishConfigDiscovery() now skip-and-log instead of publishing
//    silently-truncated JSON
//  - LOW_BATTERY_PCT promoted to #define constant; magic 15 in Jinja template
//    replaced so threshold and discovery payload stay in sync
//  - BAT_CAL_OFFSET (always 0.0, no config path) removed
//  - analogSetPinAttenuation() moved from readMoisture() to setup() — was
//    called on every wake; now called once after config is loaded
//
//  v2.5.1
//  - FOTA: add setHandshakeTimeout() to cover TLS handshake phase —
//    setTimeout() only covers socket read/write; mbedTLS handshake could
//    hang indefinitely without this. Applied to both version check and
//    binary download connections.
//
//  v2.5.0
//  - Configurable GPIO pins: moisturePin, batteryPin, reedPin stored in NVS
//    with safe defaults (0, 1, 2); settable via captive portal Advanced
//    section and MQTT remote config — accommodates hardware variations
//
//  v2.4.1
//  - Battery curve recalibrated: 3.25 V is now 0% (was 10%) based on
//    real-world observation that sensors go offline before reaching the
//    old 10% threshold; all other breakpoints rescaled proportionally
//  - HA low battery binary sensor: autodiscovered entity reports ON when
//    battery_pct <= 15%, using existing state topic (no new MQTT topic)
//  - Reed switch two-stage hold: 3s = restart, 10s = wipe config + portal;
//    log feedback at 3s mark so user knows to keep holding for full reset
//
//  v2.4.0
//  - MQTT remote config: partial JSON updates to garden/sensorN/config/set
//    apply individual settings (mqttBroker, mqttPort, mqttUser, mqttPassword,
//    syslogHost, syslogPort) without a factory reset; same validation as portal
//  - Config state published retained to garden/sensorN/config/state after
//    each change and on every boot (HA text/number entities read from here)
//  - HA MQTT autodiscovery for 6 config entities (text + number) so settings
//    are editable directly from the HA device card
//
//  v2.3.0
//  - HA MQTT autodiscovery: Restart and Reset Config button entities
//    appear automatically in the device card in Home Assistant
//  - Syslog: hostname resolved once at startup with 3 s timeout;
//    uses pre-resolved IPAddress for all sends (no per-packet DNS blocking);
//    syslog disabled for the cycle if DNS fails — no startup delay
//  - Portal input validation: octet range (0-255), port range (1–65535),
//    string length caps, control-character rejection, hostname/IP format
//    checks on mqttBroker and syslogHost; specific error message shown
//
//  v2.2.0
//  - saveConfig() takes Config struct (was 24 params)
//  - IP addresses stored as 4-byte NVS blocks (auto-migrates old per-octet keys)
//  - configLoaded now requires MQTT broker to be set
//  - Server-side validation in handleSave()
//  - handleNotFound() uses softAPIP() instead of hardcoded 192.168.4.1
//  - readMoisture() returns MoistureReading struct (was raw mV only)
//  - mqtt.disconnect() before deep sleep (at normal end of cycle)
//  - MQTT buffer size increased to 768
//  - FOTA blocked on development/test builds (version string contains '-')
//  - Syslog over UDP: buffers boot messages, flushes after WiFi connect
//  - Syslog server and port configurable in portal (default: logs:514)
//
//  v2.1.0
//  - Captive portal config on first boot
//  - Boot button hold to reconfigure without reflashing
//  - Reed switch hold to restart (external, no enclosure access needed)
//  - MQTT retained command: reset / restart (self-clearing)
//  - FOTA: automatic firmware update from GitHub Releases
//  - Firmware version in MQTT payload
//  - NTP timestamp in MQTT payload (10s timeout)
//  - Gateway, netmask and DNS configurable via portal
//  - All settings stored in NVS
// ═══════════════════════════════════════════════════════════

// Dev builds: update the SHA suffix with `git rev-parse --short HEAD` before flashing.
// Beta builds: use 2.8.0-b01, 2.8.0-b02 … (zero-padded, sortable by string compare).
#define FIRMWARE_VERSION "3.0.3"

// ── Pins ─────────────────────────────────────────────────
const int MOISTURE_PIN = 0;   // A0 — XIAO ESP32-C6
const int BATTERY_PIN  = 1;   // A1 — voltage divider midpoint
const int BTN_BOOT     = 9;   // Boot button on XIAO ESP32-C6

// ── Fixed calibration ─────────────────────────────────────
const int   DRY_MV         = 2800;
const int   WET_MV         = 1000;
const float DIVIDER_RATIO  = 2.0;
const float BAT_MIN        = 2.5;
const float BAT_MAX        = 4.3;

// ── Timing ────────────────────────────────────────────────
const int SLEEP_MINUTES      = 120;
const int AP_TIMEOUT_MIN     = 10;
const int AP_SLEEP_MIN       = 10;
const int BOOT_HOLD_MS       = 3000;
const int NTP_TIMEOUT_MS     = 10000;
// Retained commands are delivered by the broker within tens of ms of SUBACK,
// so the base window is short. Each message received extends it by
// CMD_LISTEN_GRACE_MS (capped at CMD_LISTEN_MAX_MS) so a burst — e.g. several
// config/set fields published together — is still captured in one wake.
const int CMD_LISTEN_MS       = 750;
const int CMD_LISTEN_GRACE_MS = 250;
const int CMD_LISTEN_MAX_MS   = 2000;
const int WIFI_TIMEOUT_MS    = 10000;  // max time waiting for WiFi association
const int MQTT_TIMEOUT_S     =     5;  // TCP socket timeout per connect attempt
// Safety net for retained-discovery loss after a broker restart. Must stay
// comfortably above the longest sleepMinutes (720) or the throttle never
// fires and discovery republishes on every wake.
const uint32_t DISCOVERY_REPUBLISH_S = 24 * 3600UL;

const int FOTA_VERSION_TIMEOUT_MS = 8000;   // version.txt HTTP fetch
const int FOTA_DL_TIMEOUT_MS      = 60000;  // firmware.bin download (large file)
const int FOTA_MAX_RETRIES        = 3;      // failed boots before rollback

// ── Thresholds ────────────────────────────────────────────
#define LOW_BATTERY_PCT 15   // battery_pct at which low-battery alert fires

// ── AP credentials ────────────────────────────────────────
const char* AP_PASSWORD      = "moisture";

// ── NTP ───────────────────────────────────────────────────
const char* NTP_SERVER   = "pool.ntp.org";
const long  GMT_OFFSET_S = 0;
const int   DST_OFFSET_S = 0;

// ── FOTA ─────────────────────────────────────────────────
// Stable channel: version.txt + binary from /releases/latest/download/
const char* FOTA_VERSION_URL =
  "https://github.com/mcleancraig/moisture-sensor-esp32"
  "/releases/latest/download/version.txt";
const char* FOTA_BIN_URL =
  "https://github.com/mcleancraig/moisture-sensor-esp32"
  "/releases/latest/download/moisture-sensor-esp32.ino.bin";
// Beta channel: GitHub API /releases?per_page=1 returns the newest release
// including pre-releases (which /releases/latest skips).
const char* FOTA_RELEASES_API_URL =
  "https://api.github.com/repos/mcleancraig/moisture-sensor-esp32"
  "/releases?per_page=1";
// Binary URL template for beta — tag substituted at runtime.
const char* FOTA_BIN_URL_TMPL =
  "https://github.com/mcleancraig/moisture-sensor-esp32"
  "/releases/download/%s/moisture-sensor-esp32.ino.bin";

// ── HA discovery prefix ───────────────────────────────────
const char* HA_DISCOVERY_PREFIX = "homeassistant";

// ═══════════════════════════════════════════════════════════
//  RUNTIME CONFIG — loaded from NVS
// ═══════════════════════════════════════════════════════════

Preferences prefs;

struct Config {
  int     unitNumber;
  char    wifiSSID[64];
  char    wifiPassword[64];
  bool    staticIP;
  uint8_t ip[4];
  uint8_t gw[4];
  uint8_t sn[4];
  uint8_t dns[4];
  char    mqttBroker[64];
  int     mqttPort;
  char    mqttUser[32];
  char    mqttPassword[64];
  char    syslogHost[64];
  int     syslogPort;
  // GPIO pin assignments — configurable to accommodate hardware variations
  int     moisturePin;   // default 0  (A0/GPIO0)
  int     batteryPin;    // default 1  (A1/GPIO1)
  int     sensorPowerPin; // default -1 (Disabled / Constant 3.3V rail)
  // FOTA update channel — "stable" (default) or "beta"
  char    fwChannel[8];  // selects stable (/releases/latest) or beta (/releases)
  // First cold-boot delay — minutes to sleep before sending first full reading
  int     firstBootDelayMin;  // default 15; 0 = disabled
  // Minutes to sleep between wake cycles — default SLEEP_MINUTES
  int     sleepMinutes;
} cfg;

struct MoistureReading {
  int rawMv;
  int percent;
};

bool configLoaded = false;
unsigned long sensorPowerOnTime = 0;

// ── Power optimisation: RTC memory ───────────────────────────────────────────
// RTC SRAM survives deep sleep but is cleared on hard reset and OTA restart.
// Used to gate expensive per-wake operations (NTP, FOTA, discovery) so they
// only run when actually needed rather than on every 2-hour wake cycle.
RTC_DATA_ATTR static time_t lastNtpSync   = 0;     // epoch of last successful NTP sync
RTC_DATA_ATTR static time_t lastFotaCheck = 0;     // epoch of last FOTA version check
RTC_DATA_ATTR static bool   discoveryDone = false; // true once discovery published this session

struct WifiCache {
  uint8_t bssid[6];
  uint8_t channel;
  bool    valid;
};
RTC_DATA_ATTR static WifiCache wifiCache = { .valid = false };

// Forward use of _logf() — Arduino IDE generates the prototype; macro must be
// defined before any call site (loadConfig, clearConfig, saveConfig) so it
// resolves here, not to math.h's float logf(float).
#define logf(fmt, ...) _logf(__func__, fmt, ##__VA_ARGS__)
void _logf(const char* func, const char* fmt, ...);
static bool hasValidEpoch();

// NVS magic — identifies config written by this firmware.
// Wrong value means a different firmware used our namespace; absent means
// a pre-2.5.3 sensor (backwards-compatible, magic written on next save).
const char* NVS_MAGIC_KEY   = "magic";
const char* NVS_MAGIC_VALUE = "moisture-1";
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
void loop() {
  // Intentionally empty — deep sleep reboots into setup()
}

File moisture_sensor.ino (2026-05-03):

#include <WiFi.h>
#include <PubSubClient.h>

// ═══════════════════════════════════════════════════════════
//  CONFIG — only edit these for each sensor unit
// ═══════════════════════════════════════════════════════════

// ── Single number that configures this unit ───────────────
const int SENSOR_NUMBER = 2;  // ← change this only, everything derives from it

// WiFi
const char* WIFI_SSID       = "CANDI_2.4G";
const char* WIFI_PASSWORD   = "bruteforcethis";

IPAddress GATEWAY  (192, 168,  1,   1);
IPAddress SUBNET   (255, 255, 0,   0);
IPAddress DNS      (192, 168,  1,   1);

// MQTT
const char* MQTT_BROKER     = "192.168.11.1";
const int   MQTT_PORT       = 1883;
const char* MQTT_USER       = "hass";
const char* MQTT_PASSWORD   = "hasspassword";

// Moisture calibration — recalibrate per sensor
const int   DRY_MV          = 2800;
const int   WET_MV          = 1000;
                                       // HW-390 inverted: dry > wet

// Battery
const int   BATTERY_PIN     = 1;
const float DIVIDER_RATIO   = 2;
const float BAT_CAL_OFFSET  = 0.0;
const float BAT_MIN         = 2;
const float BAT_MAX         = 5;

// Pins
const int   MOISTURE_PIN    = 0;

// Deep sleep
const int   SLEEP_MINUTES   = 1;

// HA autodiscovery prefix
const char* HA_DISCOVERY_PREFIX = "homeassistant";

// ═══════════════════════════════════════════════════════════
//  DERIVED CONFIG — do not edit
// ═══════════════════════════════════════════════════════════

// These are populated in setup() from SENSOR_NUMBER
char SENSOR_ID[16];
char SENSOR_NAME[32];
IPAddress STATIC_IP;

// State + discovery topics
char STATE_TOPIC[64];
char DISC_MOISTURE[128];
char DISC_BAT_V[128];
char DISC_BAT_PCT[128];

// ═══════════════════════════════════════════════════════════
//  GLOBALS
// ═══════════════════════════════════════════════════════════

WiFiClient   wifiClient;
PubSubClient mqtt(wifiClient);

// ═══════════════════════════════════════════════════════════
//  FUNCTIONS
// ═══════════════════════════════════════════════════════════

void goToSleep() {
  Serial.printf("Sleep     — going to sleep for %d minutes\n", SLEEP_MINUTES);
  Serial.flush();
  esp_sleep_enable_timer_wakeup((uint64_t)SLEEP_MINUTES * 60 * 1000000ULL);
  esp_deep_sleep_start();
}

// ── Moisture ───────────────────────────────────────────────

int readMoisture() {
  analogSetPinAttenuation(MOISTURE_PIN, ADC_11db);
  delay(500);

  long sum = 0;
  for (int i = 0; i < 10; i++) {
    sum += analogReadMilliVolts(MOISTURE_PIN);
    delay(10);
  }
  int avgMv = sum / 10;

  int percent = map(avgMv, DRY_MV, WET_MV, 0, 100);
  percent = constrain(percent, 0, 100);

  Serial.printf("Moisture  — raw: %dmV  →  %d%%\n", avgMv, percent);
  return avgMv;
}

// ── Battery ────────────────────────────────────────────────

float readBatteryVoltage(int &rawMv) {
  // No attenuation on A0 — internal pull-down handles the divider
  // Seeed reference uses plain analogReadMilliVolts with no attenuation set
  delay(10);

  long sum = 0;
  for (int i = 0; i < 16; i++) {   // 16 samples as per Seeed reference
    sum += analogReadMilliVolts(BATTERY_PIN);
    delay(5);
  }
  rawMv = sum / 16;

  float voltage = (rawMv / 1000.0 * DIVIDER_RATIO) + BAT_CAL_OFFSET;

  if (voltage < BAT_MIN || voltage > BAT_MAX) {
    Serial.printf("Battery   — suspicious reading %.2fV (raw: %dmV), discarding\n",
      voltage, rawMv);
    return -1.0;
  }

  Serial.printf("Battery   — raw: %dmV  →  %.2fV\n", rawMv, voltage);
  return voltage;
}


int batteryPercent(float voltage) {
  if (voltage >= 4.10) return 100;
  if (voltage >= 3.90) return 80;
  if (voltage >= 3.70) return 60;
  if (voltage >= 3.50) return 40;
  if (voltage >= 3.30) return 20;
  if (voltage >= 3.10) return  5;
  return 0;
}

// ── WiFi ───────────────────────────────────────────────────

void connectWifi() {
  if (!WiFi.config(STATIC_IP, GATEWAY, SUBNET, DNS)) {
    Serial.println("WiFi      — static IP config failed");
  }

  Serial.printf("WiFi      — connecting to %s as %s",
    WIFI_SSID, STATIC_IP.toString().c_str());

  WiFi.begin(WIFI_SSID, WIFI_PASSWORD);

  int attempts = 0;
  while (WiFi.status() != WL_CONNECTED && attempts < 20) {
    delay(500);
    Serial.print(".");
    attempts++;
  }

  if (WiFi.status() == WL_CONNECTED) {
    Serial.printf("\nWiFi      — connected, IP: %s\n",
      WiFi.localIP().toString().c_str());
  } else {
    Serial.println("\nWiFi      — failed, going to sleep");
    goToSleep();
  }
}

// ── MQTT ───────────────────────────────────────────────────

void connectMqtt() {
  mqtt.setServer(MQTT_BROKER, MQTT_PORT);
  mqtt.setBufferSize(512);   // needed for discovery payloads
  String clientId = String("garden-") + SENSOR_ID;

  Serial.printf("MQTT      — connecting to %s as %s\n",
    MQTT_BROKER, clientId.c_str());

  int attempts = 0;
  while (!mqtt.connected() && attempts < 5) {
    if (mqtt.connect(clientId.c_str(), MQTT_USER, MQTT_PASSWORD)) {
      Serial.println("MQTT      — connected");
    } else {
      Serial.printf("MQTT      — failed (rc=%d), retrying\n", mqtt.state());
      delay(500);
      attempts++;
    }
  }

  if (!mqtt.connected()) {
    Serial.println("MQTT      — could not connect, going to sleep");
    goToSleep();
  }
}

// ── HA Autodiscovery ───────────────────────────────────────
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

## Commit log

2026-05-03 feat: captive portal config on first boot
    - Add WiFi provisioning portal via AP on failed connection
    - Store all config in NVS (no hardcoded secrets)
    - MQTT credentials, sensor number, static/dynamic IP all configurable
    - AP name derived from MAC via esp_efuse (fixes all-zeros bug)
    - DNS spoofing for automatic captive portal popup on iOS/Android
    - Portal times out after 10 min, sleeps 10 min, retries WiFi
    - Piecewise linear battery percentage from real 18650 discharge curve
    - Fix esp_efuse include: use esp_mac.h
    [moisture-sensor-esp32.ino]
2026-05-04 added my current case 3mfs
    [Case.3mf, Lid.3mf, Seal.3mf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]
2026-05-04 docs: add production wiring diagram SVG
2026-05-04 Add wiring diagram section to README
2026-05-04 docs: fix wiring diagram pinout and routing
2026-05-04 Update battery voltage divider resistor values
2026-05-04 Update README with battery charging info and remove wiring
    Removed wiring section and added important notes about battery charging.
2026-05-04 Update README with connection and troubleshooting details
    Clarified instructions for connecting the sensor and added troubleshooting information regarding overheating.
2026-05-04 Update README with battery and USB connection guidance
    Clarified instructions regarding sensor overheating and battery connection.
2026-05-04 removed diode so updated docs
2026-05-04 docs: remove diode from wiring diagram, add polarity warning
2026-05-04 updated 3d models
    [Lid.3mf, Tray.3mf]
2026-05-04 updated wiring, 3d models and version number
    [Lid.3mf, Tray.3mf]
2026-05-04 added reset and reboot, TODO add ota for update
    [moisture-sensor-esp32.ino]
2026-05-05 fix to bootloop issue caused by calling undefined function
    [moisture-sensor-esp32.ino]
2026-05-05 v2.2.0: code quality, correctness fixes, FOTA dev protection, syslog (#1)
    * v2.2.0: code quality and correctness fixes
    - saveConfig() now takes const Config& instead of 24 individual params
    - IP addresses stored as 4-byte NVS blocks; loadConfig() auto-migrates
    sensors upgrading from v2.1.0 per-octet keys on first save
    - configLoaded now requires MQTT broker to be non-empty (was WiFi-only);
    prevents silent misconfiguration that caused sleep loops
    - handleSave() validates sensorNum (1-254), SSID, and broker server-side;
    returns 400 error page on bad input instead of saving garbage config
    - handleNotFound() uses WiFi.softAPIP() instead of hardcoded 192.168.4.1
    - readMoisture() returns Mo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
    [moisture-sensor-esp32.ino]
2026-05-05 fix: remove duplicate syslog implementation left after PR merge
    The pre-PR main branch contained an older syslog implementation
    (udpSyslog, cfg.syslogServer, logMessage/LOG macros, flushSyslogQueue).
    The squash-merge appended the new implementation without removing the old
    one, causing duplicate struct/variable definitions and cfg.syslogServer
    references that don't exist in the Config struct.
    Removes the old block entirely and moves #define logf before
    clearConfig()/saveConfig() so it resolves to _logf() rather than math.h.
    [moisture-sensor-esp32.ino]
2026-05-06 v2.3.0 — HA buttons, syslog DNS fix, input validation (#2)
    * feat: add HA MQTT autodiscovery for Restart and Reset Config buttons
    Publishes retained button entity configs to homeassistant/button/
    on each boot so Restart and Reset Config appear automatically in
    the Home Assistant device card. Both buttons write a retained
    payload to the existing CMD_TOPIC — the sensor picks it up on its
    next wake cycle and self-clears the message before acting on it.
    Firmware version set to 2.3.0-dev (FOTA blocked until release).
    * fix: resolve syslog hostname once at startup with 3s timeout
    beginPacket(hostname) was doing a DNS lookup on ever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
    [moisture-sensor-esp32.ino]
2026-05-07 v2.4.0: MQTT remote config with HA autodiscovery (#3)
    * chore: start v2.4.0-dev branch — MQTT remote config
    Dev build — FOTA blocked. Update SHA in FIRMWARE_VERSION with
    `git rev-parse --short HEAD` before each flash session.
    * chore: track dev SHA 671f4f2
    * chore: track dev SHA 729b596
    * chore: track dev SHA 9f6d702
    * feat: v2.4.0 MQTT remote config with HA autodiscovery
    - garden/sensorN/config/set accepts partial JSON to update individual
    settings (mqttBroker, mqttPort, mqttUser, mqttPassword, syslogHost,
    syslogPort) without a factory reset; retained message self-clears
    - garden/sensorN/config/state publishes retained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
    [moisture-sensor-esp32.ino]
2026-05-07 v2.4.1 — battery recalibration, low battery alert, reed switch two-stage hold (#4)
    * feat: recalibrate battery curve and add HA low battery alert
    Battery curve: anchored at real-world empty — 3.25 V is now 0% (was 10%)
    based on field observation that sensors go offline before reaching the old
    10% floor. All breakpoints rescaled proportionally (old 100% unchanged).
    Entries below 3.25 V dropped from the lookup table.
    Low battery alert: new HA binary_sensor autodiscovery entity (device_class:
    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
2026-05-07 v2.5.0 — configurable GPIO pins, firmware version HA entity (#6)
    * feat: configurable GPIO pin assignments for moisture, battery and reed
    Pins are now stored in NVS with safe defaults (moisturePin=0, batteryPin=1,
    reedPin=3) matching the existing hardcoded values, so all deployed sensors
    behave identically after OTA with no config change required.
    Portal: new collapsed Advanced section with three number inputs and
    client- and server-side validation (range 0-10, all pins distinct).
    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
2026-05-08 v2.5.1 — FOTA TLS handshake timeout fix (#7)
    * fix: add setHandshakeTimeout() to FOTA to prevent TLS hang
    setTimeout() on WiFiClientSecure covers socket read/write but does NOT
    cover the mbedTLS handshake phase. A slow or unresponsive GitHub CDN
    could cause the handshake to block indefinitely.
    setHandshakeTimeout(seconds) is the correct fix — applied to both the
    version check connection and the binary download connection (which opens
    a new TLS session against the CDN redirect target).
    * chore: track SHA 3d3f4b8 in FIRMWARE_VERSION
    * chore: track SHA 84d5b27 in FIRMWAR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
    [moisture-sensor-esp32.ino]
2026-05-08 chore: add CLAUDE.md — use git -C to avoid cd+git approval prompts
2026-05-08 v2.5.2 patch: security, robustness, and housekeeping (#8)
    * feat: v2.5.2 patch — security, robustness, and housekeeping fixes
    - Mask mqttPassword in publishConfigState() — publish "***" instead of
    plaintext credential to the retained MQTT config/state topic
    - Add publishMqttEntity() helper; refactor publishDiscovery() and
    publishConfigDiscovery() to detect and log snprintf truncation instead
    of silently emitting malformed JSON
    - Promote LOW_BATTERY_PCT to #define; replace magic 15 in Jinja template
    so threshold and discovery payload are always in sync
    - Remove BAT_CAL_OFFSET (always 0.0, no config path — dead code)
    - Move analogSetPinAttenuation() from readMoisture() to setup(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
    [moisture-sensor-esp32.ino]
2026-05-09 feat: NVS magic key — detect and clear stale foreign config (#9)
    * feat: add NVS magic key to detect and clear stale foreign config
    loadConfig() now checks for "moisture-1" magic in the "sensor" namespace.
    A wrong value (stale NVS from a different firmware using the same namespace)
    triggers a clear and re-configure via portal. Absent magic is left alone
    for backwards compatibility with pre-2.5.3 sensors already in the field —
    magic is written silently on the next saveConfig().
    * chore: track SHA c9ae57a in FIRMWARE_VERSION
    * chore: track SHA 30da09e in FIRMWARE_VERSION
    * fix: move #define logf before loadConfig() to avoid mat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
    [moisture-sensor-esp32.ino]
2026-05-09 feat: expose static IP / gateway / subnet / DNS in HA config entities (#10)
    * feat: expose static IP / gateway / subnet / DNS in HA config entities
    Port of the same feature from pump-controller-esp32. Allows IP network
    settings to be corrected from Home Assistant without a factory reset —
    the immediate trigger being a wrong default DNS causing NTP to time out
    on every boot.
    Changes:
    - publishConfigState(): include staticIP, ip, gw, sn, dns in JSON payload
    - publishConfigDiscovery(): add switch (static IP) + 4 text entities
    (IP Address, Gateway, Subnet Mask, DNS Server) via the per-field
    config/set/<field> subtopic pattern used by existing config entities
    - applyConfigChange(): add PF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
    [moisture-sensor-esp32.ino]
2026-05-09 feat: wake from deep sleep on reed switch via GPIO wakeup (#12)
    * feat: wake from deep sleep on reed switch via GPIO wakeup
    Magnet presentation now wakes the device immediately via
    esp_deep_sleep_enable_gpio_wakeup() rather than waiting for the next
    15-minute timer tick. The 3s/10s hold timing in checkReedSwitch() is
    unchanged — the device now wakes fast enough that the user can
    accurately time their hold from the moment the magnet touches the case.
    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
2026-05-10 fix: change default reedPin from 3 to 2 (#13)
    * fix: change default reedPin from 3 to 2
    GPIO3 on XIAO ESP32-C6 does not function as a digital input.
    GPIO2 (D2) confirmed working. Existing sensors unaffected — reedPin
    is stored in NVS and only the factory default changes.
    * chore: track SHA e3a4fc6 in FIRMWARE_VERSION
    * chore: track SHA c1a588f in FIRMWARE_VERSION
    ---------
    [moisture-sensor-esp32.ino]
2026-05-12 chore: release 2.6.2 — increase sleep to 120 minutes
2026-05-14 feat: power optimisation — skip NTP, FOTA, and discovery on routine wakes (#14)
    * feat: power optimisation — skip NTP, FOTA, and discovery on routine wakes
    NTP: ESP32 RTC persists across deep sleep; skip re-sync unless clock is
    invalid or 24h have elapsed since last sync (daily drift correction).
    FOTA: throttle GitHub version check to once per 24h via RTC memory
    timestamp. Eliminates ~8s TLS round-trip on every wake when current.
    Discovery: skip HA autodiscovery publish on normal deep-sleep wakes.
    RTC flag cleared on hard reset/OTA so it republishes after firmware
    changes. NVS timestamp forces republish after 7 days as broker safety net.
    Combined saves ~50-60% of active-cycle radio e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
    [moisture-sensor-esp32.ino]
2026-05-14 feat: beta FOTA channel + update-on-next-wake button (2.8.0)
    - Add fwChannel config ("stable"/"beta"), persisted in NVS and exposed
    as HA select entity
    - Beta channel queries GitHub /releases API (includes pre-releases),
    uses "different = update" semantics; stable channel unchanged
    - Add "Update on next wake" HA button: publishes retained MQTT flag to
    garden/<id>/update; device arms forced FOTA check, clears flag, then
    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
2026-05-15 fix: beta FOTA only uses "different=update" for actual pre-releases
    When no beta release exists yet the GitHub API returns the latest stable
    (e.g. 2.7.0). The previous "different = update" logic fired on that,
    attempted to download a 404 URL, and failed.
    Fix: on beta channel, "different = update" semantics apply only when the
    remote tag contains "-b" (a real pre-release). If the API returns a plain
    stable tag, fall back to the same promotion logic as the stable channel:
    promote any dev/beta build, or update if remote is strictly newer.
    [moisture-sensor-esp32.ino]
2026-05-15 chore: track SHA 59838ff in FIRMWARE_VERSION
2026-05-15 fix: beta channel sits tight when no beta release exists yet
    On beta channel, if the GitHub API returns a stable tag (no "-b"),
    do nothing — don't promote/downgrade to stable. "Stay on beta" is
    the contract when fwChannel is "beta". Promotion to stable only
    belongs on the stable channel (for switching back from beta).
    [moisture-sensor-esp32.ino]
2026-05-15 chore: track SHA eb1c64b in FIRMWARE_VERSION
2026-05-15 fix: allow beta builds to promote to stable when channel switched back
    isDev (any '-') was blocking FOTA on stable channel for beta builds like
    2.8.0-b01, preventing them from promoting to the latest stable release.
    Split the concept: isDevBuild (-dev. suffix) guards against accidental
    OTA of work-in-progress builds; isDev (any '-') is kept for the
    promotion logic so beta builds correctly fall through on the stable
    channel and update to latest stable.
    [moisture-sensor-esp32.ino]
2026-05-15 chore: release 2.8.0 — revert sleep to 120m, fix log messages, bump version
    - Sleep interval restored to 120 minutes (was 5 for testing)
    - FOTA channel-switch log messages: "switching from beta/stable to stable/beta"
    rather than "promoting dev/beta build to stable"
    - FIRMWARE_VERSION 2.8.0
    [moisture-sensor-esp32.ino]
2026-05-16 chore: refactor mqtt connected check; add CLAUDE.md coding guidelines
    Remove redundant if (mqtt.connected()) wrapper in setup() — connectMqtt()
    already sleeps on failure so we are always connected past that call.
    [moisture-sensor-esp32.ino]
2026-05-16 feat: standardisation — unitNumber, fw_version, rssi, semver fix, diagnostics
    - Rename sensorNumber → unitNumber (NVS key sensorNum unchanged, no factory reset)
    - State payload: fw → fw_version, add rssi field; bump payload buffer 384 → 512
    - Fix FOTA semver comparison: strcmp breaks when minor ≥ 10 (2.10.0 < 2.9.0);
    add isNewerVersion() using sscanf integer parse; apply to stable and beta paths
    - Full wake/reset reason logging: esp_reset_reason() at boot, switch on wakeup_cause
    covering timer, GPIO and unexpected cases
    - Heap monitoring: free + min-free heap logged after WiFi connects and after FOTA
    - validateConfig() checks moisturePin/batteryPin/reedPin for conflicts at boot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
    [moisture-sensor-esp32.ino]
2026-05-16 chore: update HA dashboard — add RSSI chip, fix last_seen entity IDs
    - Add RSSI chip (mdi:wifi) to mushroom-chips-card for all 6 sensor units
    (new rssi field registered via HA discovery in v2.9.0)
    - Fix sensor.garden_sensor_3_last_seen → sensor.garden_moisture_sensor_3_last_seen
    - Fix sensor.garden_sensor_4_last_seen → sensor.garden_moisture_sensor_4_last_seen
    - Add missing name: type: entity to unit 3 last_seen card
2026-05-16 feat: add RSSI HA discovery entity (backs dashboard RSSI chips)
    RSSI was already in the state payload; this registers the HA sensor so
    the entity exists in autodiscovery (device_class: signal_strength, dBm).
2026-05-16 fix: extend isNewerVersion() to compare -bNN beta suffix; bump to 2.9.0-b02
    Beta-to-beta FOTA now works: 2.9.0-b01 → 2.9.0-b02 correctly resolves
    as newer when the major.minor.patch triplet is equal. Also handles
    stable > beta of same version (2.9.0 > 2.9.0-b02) without the isDev
    fallback.
    [moisture-sensor-esp32.ino]
2026-05-16 chore: add update channel chip to all sensor dashboard cards
2026-05-16 chore: release 2.9.0 — set stable FIRMWARE_VERSION
2026-05-16 chore: remove homeassistant/ folder
    Dashboard moved to mcleancraig/pump-and-moisture-dashboards.
2026-05-27 feat: first boot delay — skip moisture on cold power-cycle boot (v2.10.0)
    On ESP_RST_POWERON, the device now publishes all stats except moisture
    (battery, RSSI, firmware, timestamp) then sleeps for firstBootDelayMin
    (default 15 min) before waking for the first full data set. This avoids
    a spurious near-zero reading while the sensor is in open air after
    battery insertion.
    firstBootDelayMin is stored in NVS, configurable via MQTT config/set/
    and exposed as a HA number entity (0 = disabled, range 0–120 min).
    goToSleep() now accepts an explicit minutes argument; all call sites
    updated.
    [moisture-sensor-esp32.ino]
2026-05-27 fix: first boot delay — portal save wrote 0 to NVS, SW reset bypassed check (v2.10.1)
    Two bugs prevented the first-boot delay from firing on new sensors:
    1. handleSave() built Config c={} (zero-init), so firstBootDelayMin was
    saved as 0 to NVS, discarding the default 15. Fixed by copying
    cfg.firstBootDelayMin into c before calling saveConfig().
    2. After portal config, ESP.restart() produces reset_reason=SW (3), not
    ESP_RST_POWERON (1), so the first real operational boot never passed
    the POWERON check. Fixed by adding a one-shot NVS flag (firstBootPend)
    written by handleSave() and read+cleared by setup() via the new
    checkAndClearFirstBootPending() helper.
    [moisture-sensor-esp32.ino]
2026-05-27 feat: NVS magic tightened, CHANGELOG/TODO housekeeping (v2.10.2)
    NVS magic (loadConfig): absent key now clears namespace and falls through
    to portal, same as wrong-value. Pre-2.5.3 backwards-compat holdover
    removed — all deployed sensors have written the magic key on a save.
    CHANGELOG: add v2.10.0, v2.10.1, v2.10.2 entries; fix v2.8.0 date.
    TODO: remove per-device AP password (won't implement); mark reed switch
    testing as skipped; cross off FOTA downgrade protection (done in v2.9.0).
    [moisture-sensor-esp32.ino]
2026-05-27 chore: fix build.sh arduino-cli path — use full path from Arduino IDE.app
2026-05-29 feat: v2.11.0 — NVS magic fix, first boot delay fix, AP name, boot logging
    - NVS magic: revert absent-magic wipe (v2.10.2 regression); write magic
    passively on successful loadConfig() to migrate pre-2.5.3 sensors
    - First boot delay: handleSave() now uses default 15 min when config was
    never loaded, fixing post-wipe portal provisioning silently saving 0
    - Portal AP name: MOISTURE-AABBCC (last 3 MAC bytes) instead of full 12-char
    - Boot logging: human-readable reset reason strings; first-boot-delay status
    logged on cold boots; delay(50) in goToSleep() for sleep log reliability
    [moisture-sensor-esp32.ino]
2026-07-01 chore: release 2.11.0 — set stable FIRMWARE_VERSION
    Promote the confirmed 2.11.0-b01 beta to stable: drop the -bNN suffix,
    date the CHANGELOG entry as the stable release, and mark the superseded
    NVS magic TODO item done (2.11.0 replaced 2.10.2's clear-on-absent
    tightening with passive migration).
    Claude-Session: https://claude.ai/code/session_01BbEJrdAcUr2t469yYMXPjg
    [moisture-sensor-esp32.ino]
2026-07-01 feat: v3.0.0 — rework MQTT controls, add configurable sleep interval
    Remove the Restart button/cmd (redundant now the device restarts every
    wake anyway), the Reed Switch Pin MQTT/HA control (reedPin reverts to
    portal-only; the reed switch hardware/wake logic is untouched), and the
    Update-on-next-wake button/flag (routine FOTA already checks every wake).
    Add a Sleep Interval MQTT/HA control (config/set/sleepMinutes, 1-720 min,
    default 120) so the wake cycle no longer requires a reflash to change.
    Includes cleanup-mqtt-retained.sh to clear the retained broker state
    (discovery configs + the update flag) the removed controls leave behind.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
    [moisture-sensor-esp32.ino]
2026-07-02 revert: restore force-FOTA-check control as "Force check on next wake" (3.0.0-b02)
    b01 removed the Update-on-next-wake button on the theory that routine FOTA
    (every wake) made it redundant — but that check is throttled to once per
    24h, and this button was the only remote way to bypass the throttle on
    demand. Confirmed the hard way: a beta-channel test device sat on a stale
    build because nothing could force an immediate recheck after switching its
    channel. Restored under a clearer name; mechanism is unchanged from b01.
    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
    [moisture-sensor-esp32.ino]
2026-07-04 feat: Add configurable on-demand sensor power pin support
    - Add sensorPowerPin config field to Config struct (stored in NVS as powerPin).
    - Support -1 to indicate continuous rail power (default), with zero-migration safety.
    - Drive power pin HIGH early during boot/wake to overlap stabilization in parallel.
    - Automatically calculate fractional remaining stabilization window in readMoisture() or use a quick 200ms ADC reference stabilization window when continuous.
    - Tri-state the pin during deep sleep (mode INPUT / LOW) to completely eliminate leakage current.
    - Add Captive Portal setup input field with client/server validation.
    - Fully integrate MQTT remote config changes, HA Discovery entity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
    [moisture-sensor-esp32.ino]
2026-07-07 docs: document GPIO sensor power-gating wiring and config
    Update README hardware table, wiring diagram, and notes to reflect that
    HW-390 VCC connects to D4 (GPIO4) rather than the 3V3 rail. Explains
    the sensorPowerPin config portal option, recommends D4, and notes the
    fallback for boards without power-gating wired.
2026-07-07 feat: add FOTA rollback guard with NVS boot-failure counter
    Adds an NVS-backed boot-health check (fota namespace) that tracks
    consecutive failed boots after a FOTA flash. After FOTA_MAX_RETRIES (3)
    boots without a successful MQTT publish, the firmware switches the active
    OTA partition back to the previous version and restarts.
    On the recovered firmware's first healthy wake, a ROLLED BACK syslog
    line is emitted so Grafana can alert:
    {job="syslog"} |= `FOTA — ROLLED BACK`
    A badVer NVS key prevents re-downloading the rejected version on
    subsequent FOTA checks until a newer release is available.
    [moisture-sensor-esp32.ino]
2026-07-15 Release 3.0.2 (#34)
    * feat: republish MQTT discovery every 2 h (was 7 days) (#32)
    Reduces recovery time after broker restart or retained-message loss from
    up to 7 days to one wake cycle (~2 h). Also updates the skip log line
    from days to minutes to match the new window.
    * fix: use single % in MQTT discovery unit_of_measurement (#33)
    The extra field strings are passed as %s arguments to snprintf, not as
    the format string, so %% is emitted literally as %% in the JSON payload.
    HA's validator rejects unit_of_measurement: "%%" for battery and moisture
    device classes, causing entities to fail creation after an entity registry
    reset or f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
    [moisture-sensor-esp32.ino]
2026-08-17 perf: cut per-wake awake time — listen window, discovery throttle, timing logs
    Three changes aimed at per-wake energy, measurable from syslog:
    - Fix HA discovery republishing every wake. The threshold was >2h, exactly
    equal to the default SLEEP_MINUTES of 120, so it always tripped and the
    throttle never actually throttled. ~20 retained payloads were republished
    every wake. Now DISCOVERY_REPUBLISH_S (24h), clear of the 720-minute
    maximum sleepMinutes.
    - Shorten the MQTT listen window from a fixed 2000ms to 750ms. Retained
    commands arrive within tens of ms of SUBACK, so most of that window was
    idle at full radio power. Inbound messages extend it 250ms at a time up
    to the old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
    [moisture-sensor-esp32.ino]
2026-08-18 docs: refresh README for 3.0.1-3.0.3 changes (#36)
    Reconciles the README against what the firmware actually does now:
    - Discovery republish is daily, not every 2 hours (changed in 3.0.3)
    - Remove the reed switch from Features, the wiring diagram and the
    reconfiguration methods — the code was fully removed in 3.0.1-b02 and
    reedPin is no longer a config field
    - Add the new 3.0.3 timing log lines to the syslog reference, plus the
    fast-connect fallback line, so the fleet can be measured from syslog
    - Document the beta release process. It has been in continuous use since
    2.8.0 but was never written down: the -bNN convention, why the two
    channels need different release assets (beta re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
